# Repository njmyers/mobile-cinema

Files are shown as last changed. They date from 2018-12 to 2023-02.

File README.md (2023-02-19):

## Description

Mobile cinema is an audio/visual presentation unit designed for the rough conditions of the field. It is a solar powered, efficient and durable system that can endure the hardships associated with transportation, inclement weather and outdoor conditions. It emphasizes power efficiency and usability over features to create a product that satisfies the use case as cleanly as possible.

The cinema uses a pre-fabricated case with custom electronic and physical parts. Physical parts are fabricated using 3D printing and 2D laser cutting. The materials used are PETG for printing and matte acrylic for 2D cut parts. The parts are then assembled using a combination of structural plastic adhesives and M3 hardware. Electronic parts include some store bought parts such as the TV and solar panel as well as custom circuit boards for routing and switching. All electronics are mounted using printed parts and wiring is done by hand.

The end result is a highly durable, flexible and efficient product that performs very well under harsh conditions and can be easily operated after a simple training session.

## BOM

Parts lists are located in this repository as well as the following [google sheet](https://docs.google.com/spreadsheets/d/1YABbkeHETHl9nhduOOJQ0aeivhLUgdqu8qCclFDEOm0/edit?usp=sharing).

## Photos

Village Video v4.1 Product Photo

_Village Video v4.1 Product Photo_

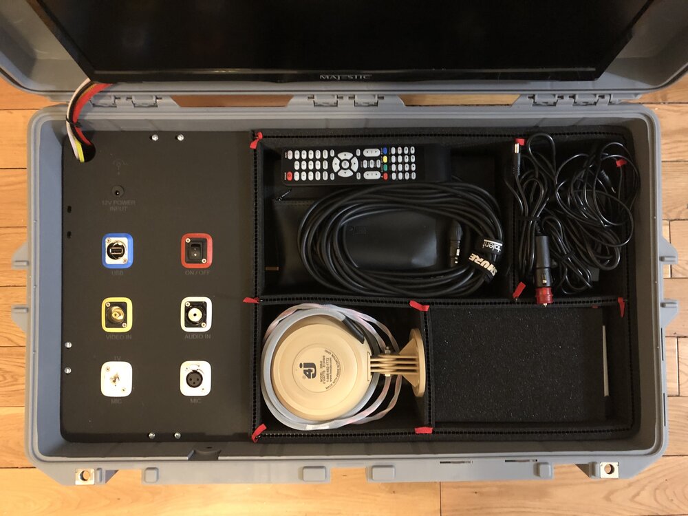
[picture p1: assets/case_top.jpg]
Village Video v4.1 Top View


_Village Video v4.1 Top View_

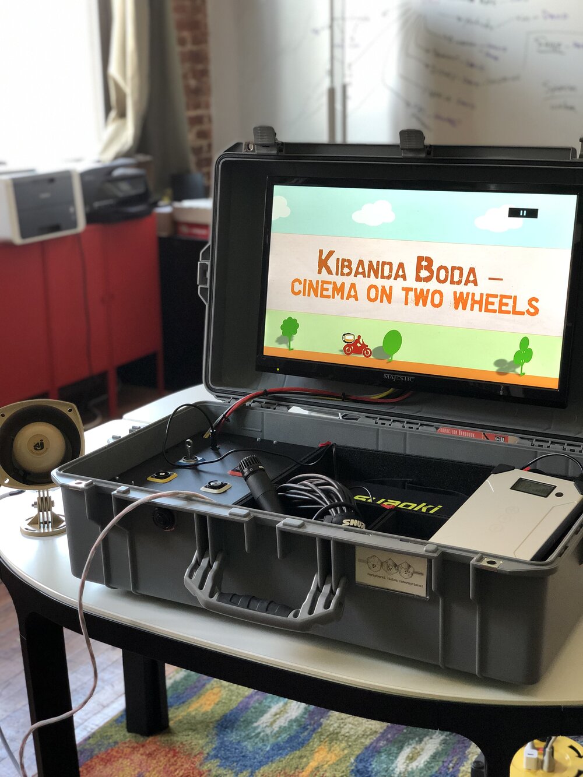
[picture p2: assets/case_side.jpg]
Village Video v4.1 In Use


_Village Video v4.1 In Use_

## Links

- PVI International [Project Description](https://www.pvinternational.org/projects/kibanda-boda/)
- PVI International [v4.0 Release](https://www.pvinternational.org/news/pvi-launches-village-video-4-0/)

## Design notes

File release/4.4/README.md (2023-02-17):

### v4.4 Notes

This version has some great improvements. Most notable is the addition of a full depth bracket system for affixing the io panel, a power routing board, and fully transformer isolated audio inputs.

All boards now feature BOMs as well as an updated parts list for other commercially bought parts. Overall time to assemble a unit should be much less following these improvements.

### Changes

- Fixed terminal blocks for all connectors
- Transformer isolated audio inputs
- Full depth brackets for io board mounting
- Power routing board for easier assembly
- BOMs and parts lists
- Addition of TV spacer print file for different TV versions

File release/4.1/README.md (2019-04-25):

### v4.1 Follow-up Notes

Version 4.1 had some great improvements on v4.0. Some of the most notable improvements were a dedicated circuit board, use of heat-set brass threaded inserts, and the centering of the TV. Here are some notes that could be useful for improvements in the next version.

#### Electrical Assembly

Version 4.1 differed from 4.0 by introducing the first integrated circuit board that was done specifically for this project. This was a very simple circuit as it only included an audio routing section, a transformer to isolate the audio input from the television and a passive resistor network to sum the TV channels to mono. It greatly reduced assembly time by using molex connectors and reduced the amount of internal cabling needed to properly route all of the signals. Considerations for next steps would be the addition of a onboard microphone preamp and onboard audio amplifier so that all electronics are self contained. At this point the only connections would be to the panel.

#### Physical Assembly

One of the most difficult things about this version is the physical assembly of the unit. We are currently using 3D printed parts in PETG with heat-set brass inserts. So far we have been quite happy with the mechanical durability with this process but the assembly of all of the parts continues to be prone to error. Below are some considerations for a future version that would increase the precision of the assembly and also reduce the amount of time required

1. Combine printed parts into one single 'insert' that can fit directly into the pelican case.

   - Positives

     - Able to have precise measurements
     - No need to use clamps while epoxying the insert
     - Better durability from one piece
     - Better adhesion from increased surface area
     - Faster assembly

   - Negatives

     - Need to precisely model interior of pelican case
     - Subject to change if case undergoes design changes
     - More difficult to print a single piece of this size
     - Uses more material to print

   Overall I think the positives outweigh the negatives. With a single piece printed piece we could easily apply epoxy without the need for tools or special equipment and simply position the insert into place. With the brass threaded inserts this provides a very quick and easy way to get repeatably good results.

2. Change power switch labeling for on/off vertical alignment

   - Positives

     - More Clear

3. Use a detachable speaker cable

   - Positives

     - Less Tangle
     - Easier to put away

   - Negatives

     - Another jack on the electrical panel
     - Another possible point of failure

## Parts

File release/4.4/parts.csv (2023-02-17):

Part Name | Manufacturer | Model | Quantity | Unit Price | Price | Link
Televsion | Majestic | MJLED222GS | 1 | $610.00 | $610.00 | https://majesticelectronics.us/led-tv/10-majestic-22-led-tv-12v-fhd-global-tuners-dvd-usb-mmmi-low-power-current.html
Case | Pelican | 1605 Air | 1 | $269.95 | $269.95 | https://www.pelican.com/us/en/product/cases/air/1605/
Packing | Pelican | 1605 Trek Pak | 1 | $154.95 | $154.95 | https://www.amazon.com/TrekPak-Insert-Pelican-1605-Case/dp/B01N43TIK2?s=electronics
Battery | Voltaic | v88 | 3 | $129.00 | $387.00 | https://voltaicsystems.com/v88/
Solar Panel | AimTom | ASP-60 | 1 | $169.00 | $169.00 | https://www.aimtom.com/product/asp60/
Microphone | Shure | SM57 | 1 | $99.00 | $99.00
Speaker | Fourjay | 306-8 Little Big Horn | 1 | $52.98 | $52.98
Mic Preamp | Rolls | MP13 | 1 | $56.00 | $56.00
Power Amp | Pyle | PLMRA120 | 1 | $37.98 | $37.98
3.5mm Audio Jack | Switchcraft | EH35MMSSCB | 1 | $12.69 | $12.69
RCA Video Jack | Neutrik | NF2D-B-0 | 1 | $4.34 | $4.34
Speaker Jack | Switchcraft | E11 | 1 | $4.98 | $4.98
USB Jack | Neutrik | NAUSB-W | 1 | $5.37 | $5.37
Microphone Jack | Neutrik | NC3FD-L-1 | 1 | $3.00 | $3.00
Power Switch | Switchcraft | EHRRSLB | 1 | $6.98 | $6.98
Audio Switch | Switchcraft | EHTSLB | 1 | $6.89 | $6.89
Yellow Gasket | Neutrik | SCDP-4 | 1 | $2.46 | $2.46
Blue Gasket | Neutrik | SCDP-6 | 1 | $2.46 | $2.46
Red Gasket | Neutrik | SCDP-2 | 1 | $2.46 | $2.46
White Gasket | Neutrik | SCDP-9 | 4 | $2.46 | $9.84
Wire | Consolidated | Stranded 18AWG | 2 | $5.79 | $11.58
USB Cable | Generic | USB2.0 A to B 3.3ft | 1 | $1.42 | $1.42
Mic Cable 30 ft. | Talent | MCB30 | 1 | $13.48 | $13.48
Heatshrink | NTE | Black 2:1 4” | 1 | $3.29 | $3.29
Power Plug | PartsExpress | 2.1 x 5.5 X 9.5mm DC | 3 | $0.96 | $2.88
¼” Mono Speaker Plug | Neutrik | NP2X-WT ¼ Mono | 1 | $4.15 | $4.15
¼” Mono Amp Plug | PartsExpress | ¼” Mono Right Angle | 1 | $1.53 | $1.53
XLR Microphone Plug | Neutrik | NC3MRX Male 90 Deg | 1 | $7.34 | $7.34
3.5mm Audio Plug | Amphenol | KS3P 3.5mm Stero | 1 | $2.20 | $2.20
RCA Right Angle | PartsExpress | Gold RCA Right Angle | 1 | $4.39 | $4.39
CircuitBoard | OSH Park | See Eagle Files | 1 | $5.00 | $5.00
Transformer | Xicon | XFMR STG 600CT-600CT | 1 | $2.97 | $2.97
Resistor ¼ W 470Ω 5% | Ohmite | OD471JE | 2 | $0.84 | $1.68
Resistor ¼ W 20KΩ 5% | Ohmite | OK2035E-R52 | 1 | $0.10 | $0.10

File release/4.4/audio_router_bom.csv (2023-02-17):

Mouser Part Number | Mfr Part Number | Description | Quantity | Unit Price | Cost
71-RL07S-G-20K | RL07S203GB14 | Metal Film Resistors - Through Hole 1/4watt 20Kohms 2% | 5 | $0.58 | $2.90
71-RL07S-G-470 | RL07S471GB14 | Metal Film Resistors - Through Hole 1/4watt 470ohms 2% | 2 | $0.51 | $1.02
71-RL07S-G-8.2K | RL07S822GB14 | Metal Film Resistors - Through Hole 1/4watt 8.2Kohms 2% | 1 | $0.46 | $0.46
810-FG28C0G1H102JNT6 | FG28C0G1H102JNT06 | Multilayer Ceramic Capacitors MLCC - Leaded Multilayer Ceramic Capacitors MLCC - Leaded RAD 50V 1000pF C0G 5% LS:5mm | 1 | $0.28 | $0.28
553-TY311P | TY-311P | Audio Transformers / Signal Transformers Audio Transformers / Signal Transformers AUDIO XFMR FCC68 XFMR 600:600 0mADC/TY-311P | 1 | $5.60 | $5.60
42TM016-RC | 42TM016-RC | Audio Transformers / Signal Transformers XFMR STG 600CT-600CT | 1 | $4.42 | $4.42
651-1985836 | 1985836 | Fixed Terminal Blocks MKDS 1/3-3.81 HT | 3 | $2.40 | $7.20
651-1985823 | 1985823 | Fixed Terminal Blocks MKDS 1/2-3.81 HT | 1 | $1.59 | $1.59

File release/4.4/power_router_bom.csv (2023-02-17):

Mouser Part Number | Mfr Part Number | Description | Quantity | Unit Price | Cost
651-1985823 | 1985823 | Fixed Terminal Blocks MKDS 1/2-3.81 HT | 4 | $1.59 | $6.36

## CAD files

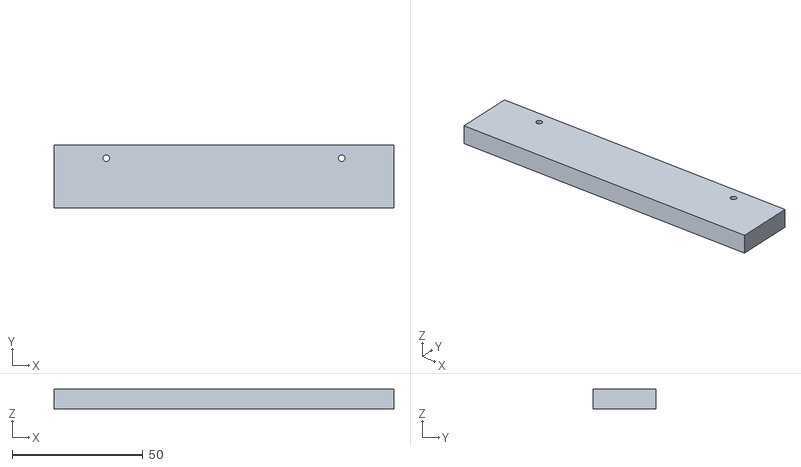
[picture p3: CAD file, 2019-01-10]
release/4.0/amplifier-mount-4.0.stl
130.0 x 24.0 x 7.50

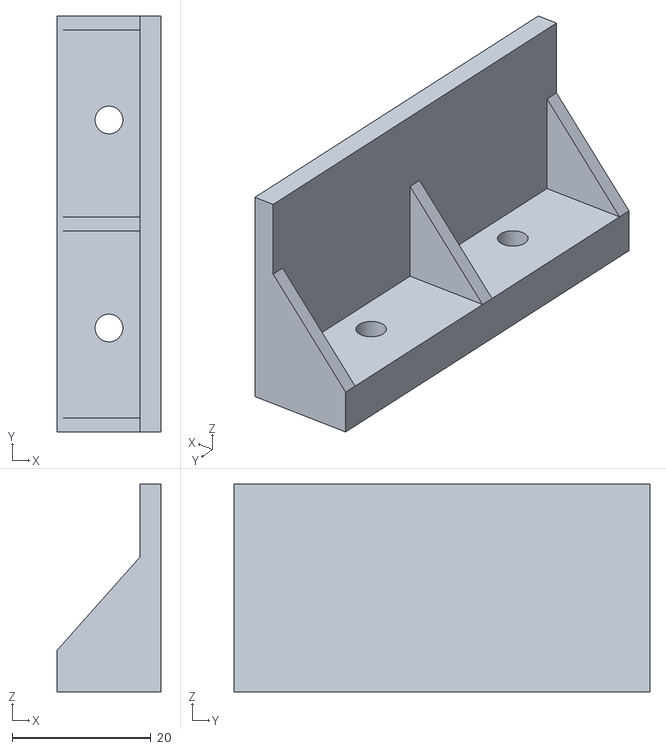
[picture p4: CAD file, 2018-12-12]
release/4.1/panel-bracket.4.1.stl
15.0 x 60.0 x 30.0

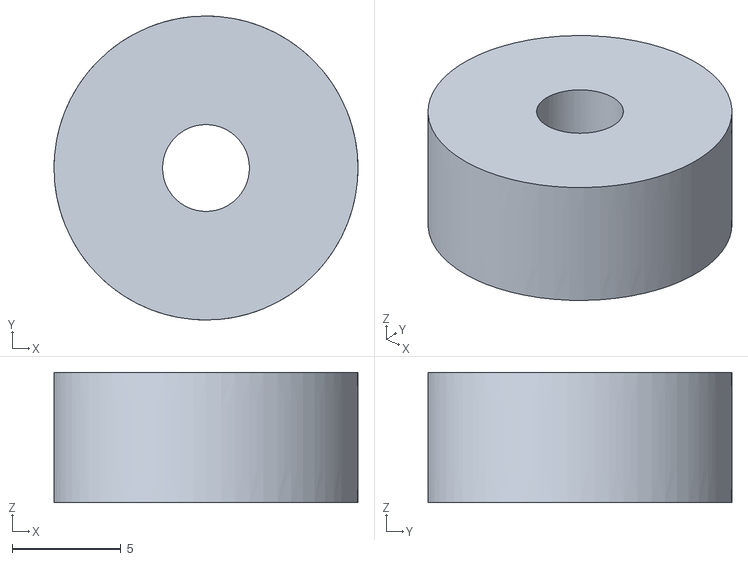
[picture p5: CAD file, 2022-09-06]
release/4.4/tv_mount_spacer.stl
14.0 x 14.0 x 6.00

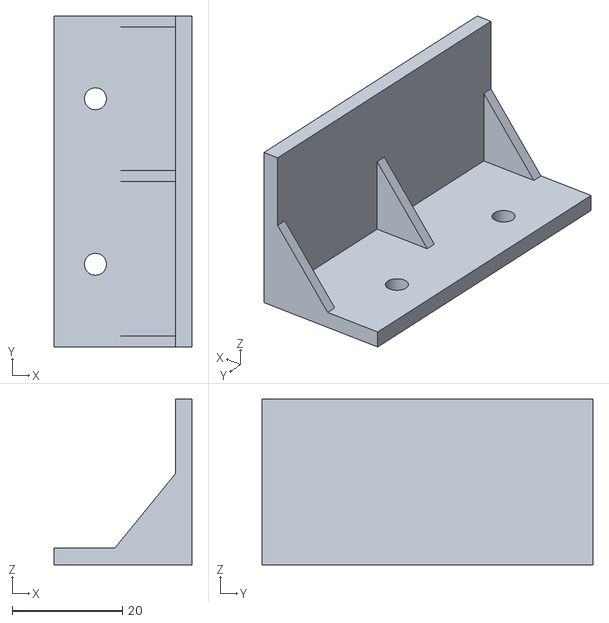
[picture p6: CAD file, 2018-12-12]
release/4.0/panel-bracket.4.0.stl
25.0 x 60.0 x 30.0

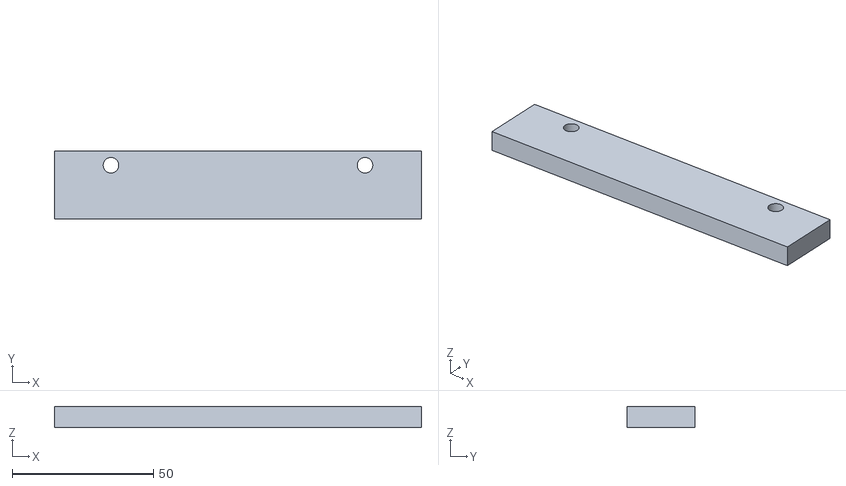
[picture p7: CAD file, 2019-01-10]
release/4.2/amplifier-mount-4.2.stl
130.0 x 24.0 x 7.50

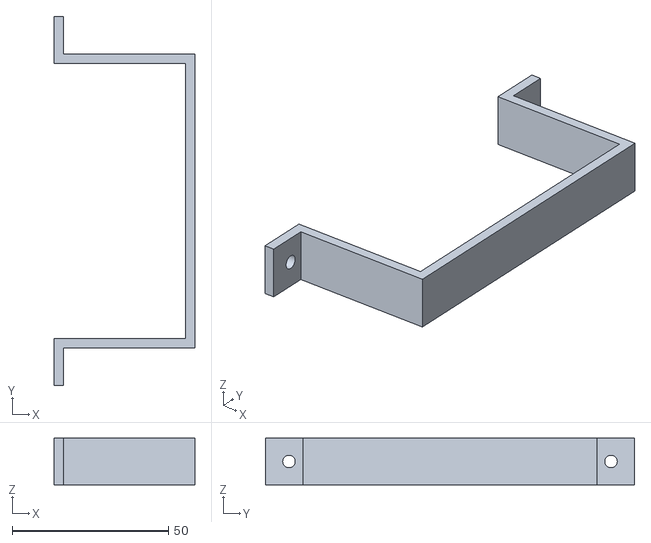
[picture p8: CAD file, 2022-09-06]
release/4.4/mic_preamp_bracket.stl
45.0 x 118.0 x 15.0

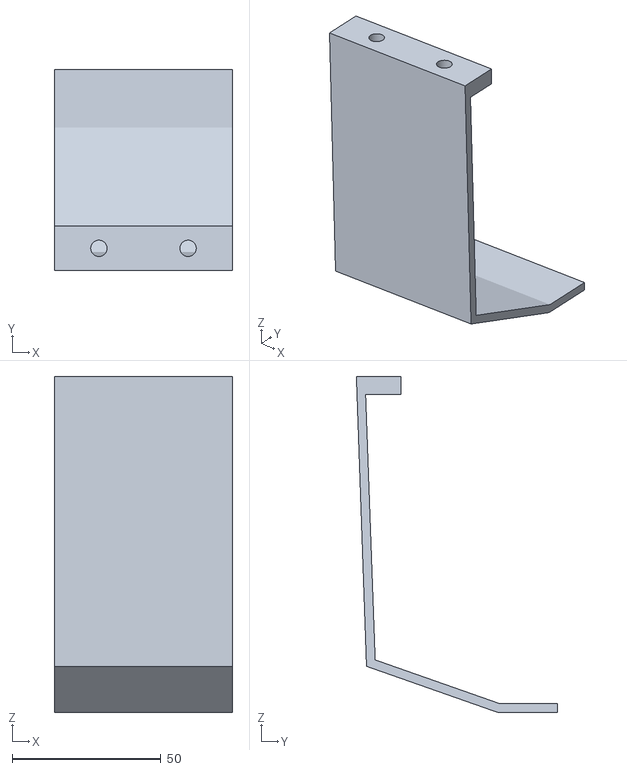
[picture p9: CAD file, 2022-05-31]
release/4.4/small_panel_bracket.stl
60.0 x 67.7 x 113.0

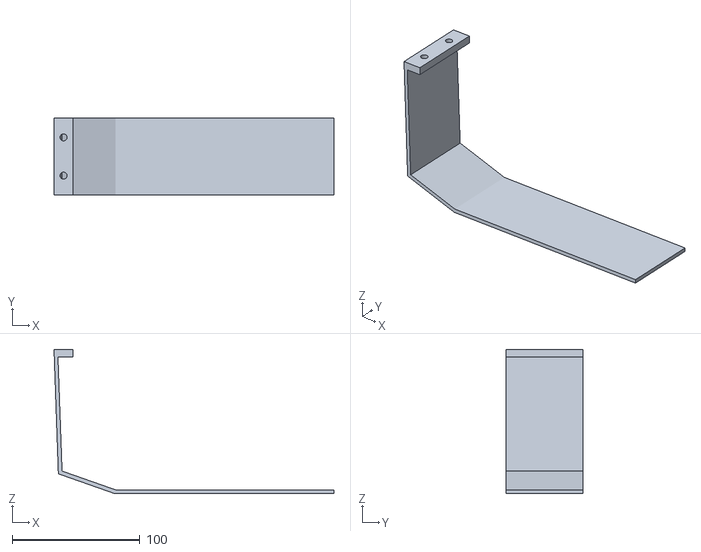
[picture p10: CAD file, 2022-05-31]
release/4.4/large_panel_bracket.stl
219.2 x 60.0 x 113.0

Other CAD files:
release/4.2/panel-bracket.4.2.stl
src/physical/electrical_panel.3dm
src/physical/panel_bracket.3dm

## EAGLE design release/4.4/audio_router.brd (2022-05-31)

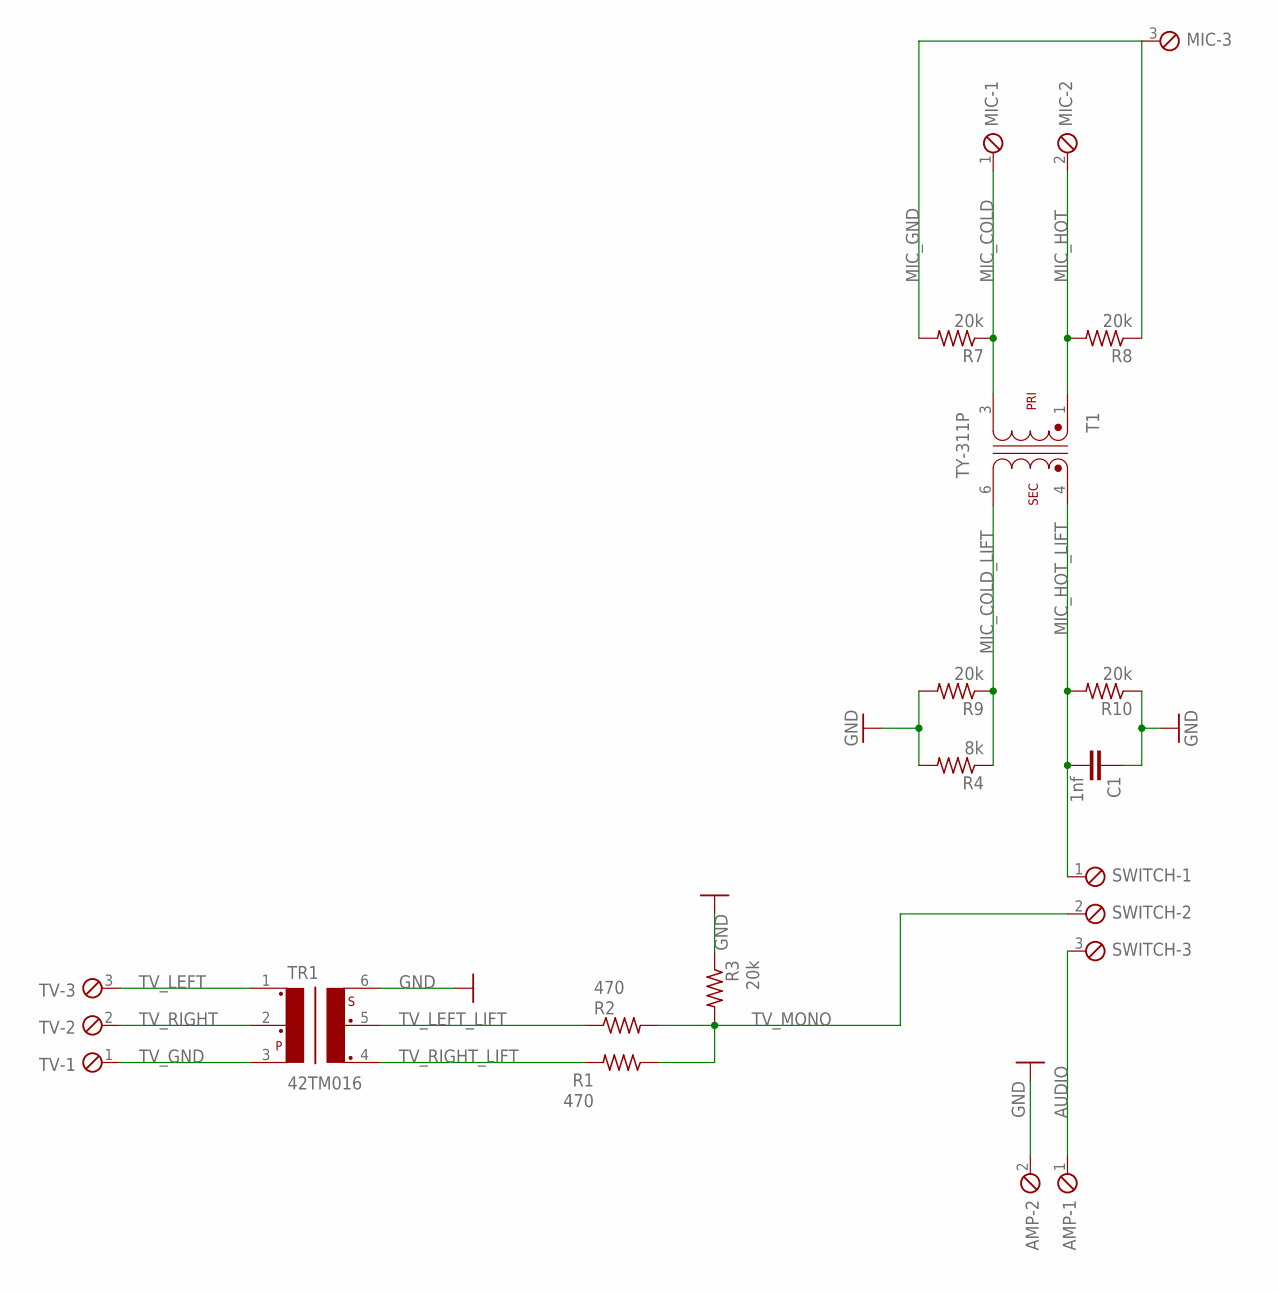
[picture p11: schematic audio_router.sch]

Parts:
AMP: TB3POL; 2POL381
C1: 1nf; CAP-PTH-SMALL-KIT
MIC: TB3POL; 3POL381
R1, R2: 470; 0204/7
R3, R7, R8, R9, R10: 20k; 0204/7
R4: 8k; 0204/7
SWITCH: TB3POL; 3POL381
T1: TY-311P; XFMR_TY-311P
TR1: 42TM016; 42TM
TV: TB3POL; 3POL381

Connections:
AUDIO: AMP.1, SWITCH.3
GND: AMP.2, C1.1, R3.1, R4.2, R9.2, R10.1, TR1.6
MIC_COLD: MIC.1, R7.1, T1.3
MIC_COLD_LIFT: R4.1, R9.1, T1.6
MIC_GND: MIC.3, R7.2, R8.1
MIC_HOT: MIC.2, R8.2, T1.1
MIC_HOT_LIFT: C1.2, R10.2, SWITCH.1, T1.4
TV_GND: TR1.3, TV.1
TV_LEFT: TR1.1, TV.3
TV_LEFT_LIFT: R2.1, TR1.5
TV_MONO: R1.1, R2.2, R3.2, SWITCH.2
TV_RIGHT: TR1.2, TV.2
TV_RIGHT_LIFT: R1.2, TR1.4

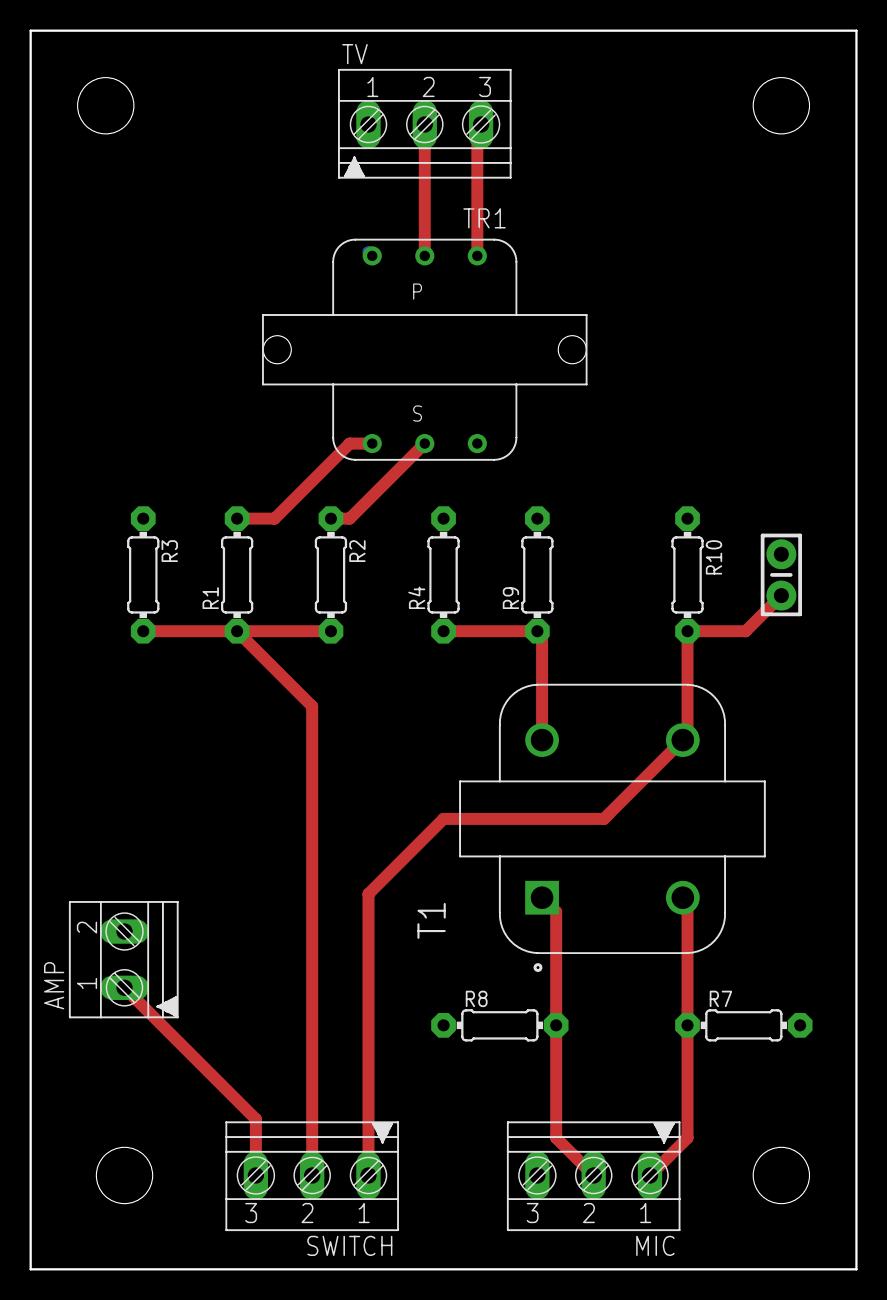
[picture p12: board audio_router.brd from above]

Board: 2 copper layers, 55.9 x 83.8 mm, 15 parts (0 on the bottom side), 13 nets.

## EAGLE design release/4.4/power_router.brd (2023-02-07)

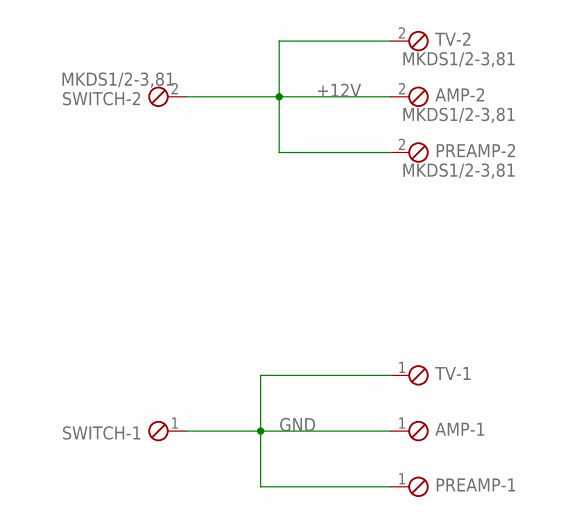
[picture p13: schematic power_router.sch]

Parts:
AMP: MKDS1/2-3,81; 2POL381
PREAMP: MKDS1/2-3,81; 2POL381
SWITCH: MKDS1/2-3,81; 2POL381
TV: MKDS1/2-3,81; 2POL381

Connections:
+12V: AMP.2, PREAMP.2, SWITCH.2, TV.2
GND: AMP.1, PREAMP.1, SWITCH.1, TV.1

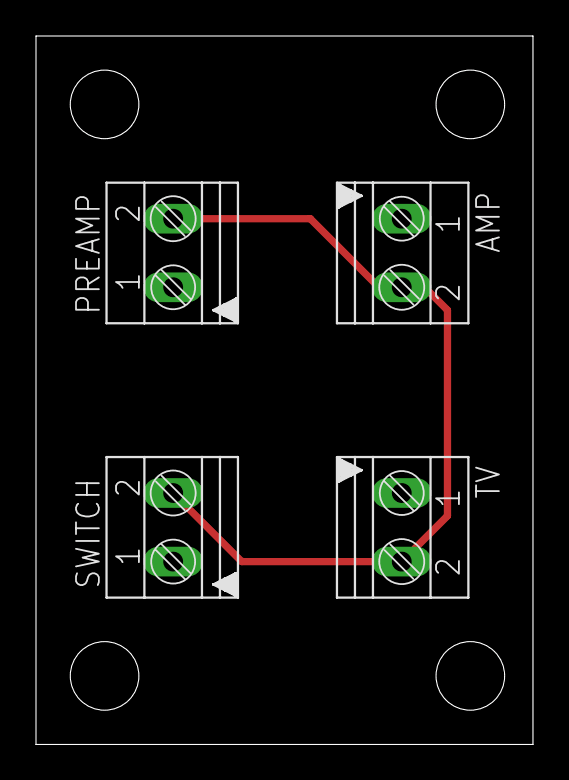
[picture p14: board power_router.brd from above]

Board: 2 copper layers, 27.6 x 39.4 mm, 4 parts (0 on the bottom side), 2 nets.

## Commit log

2018-11-24 created schematic for audio circuit
    [transfo_schematic.brd, transfo_schematic.sch]
2018-12-12 added electrical panel
    [electrical-panel.3dm]
2018-12-12 added panel brackets
    [panel-bracket.3dm, panel-bracket.4.0.stl, panel-bracket.4.1.stl]
2019-01-10 added rhino files for amplifier mounting panels
    [amplifier-mount.3dm]
2019-01-10 added new export files form amplifier-mount and panel-bracket and new source files for panel-bracket
    [amplifier-mount-4.0.stl, amplifier-mount-4.1.stl, panel-bracket.3dm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]
2019-03-11 Changed directory structure
    [amplifier-mount-4.0.stl, amplifier-mount-4.1.stl, amplifier-mount.3dm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]
2019-04-25 Add v4.2 electrical panel
    [electrical-panel.3dm]
2019-04-25 Copied v4.1 reusable designs to v4.2
    [amplifier-mount-4.2.stl, panel-bracket.4.2.stl]
2021-06-19 Add parts list
    [parts-list.csv]
2021-12-11 New router board
2022-05-31 v4.3 board design
    [transfo_schematic.brd, transfo_schematic.sch]
2022-05-31 v4.4 board design
    [transfo_schematic.brd, transfo_schematic.sch]
2022-05-31 Add io-panel directory
    [electrical-panel.3dm, large-panel-bracket.stl, panel-bracket.3dm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]
2022-05-31 Add 4.3 release files
    [large-panel-bracket.stl, small-panel-bracket.stl]
2022-09-06 Add additional source files
    [amplifier-mount.3dm, large-panel-bracket-4.3.stl, mic-preamp-bracket.stl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]
2023-02-07 Add new power_router board and schematic
    [power_router.brd, power_router.sch]
2023-02-07 Move files
    [power_router.brd, power_router.sch]
2023-02-17 Add BOMs
    [audio_router_bom.csv, power_router_bom.csv]
2023-02-17 Update parts data
    [parts.csv]
2023-02-17 Create 4.4 release save point
    [audio_router.brd, audio_router.sch, audio_router_bom.csv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]

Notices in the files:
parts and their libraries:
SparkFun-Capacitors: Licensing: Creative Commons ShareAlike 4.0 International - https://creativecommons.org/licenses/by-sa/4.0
